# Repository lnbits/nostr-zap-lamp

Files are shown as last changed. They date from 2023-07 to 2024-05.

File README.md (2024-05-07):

# Nostr Zap Lamp

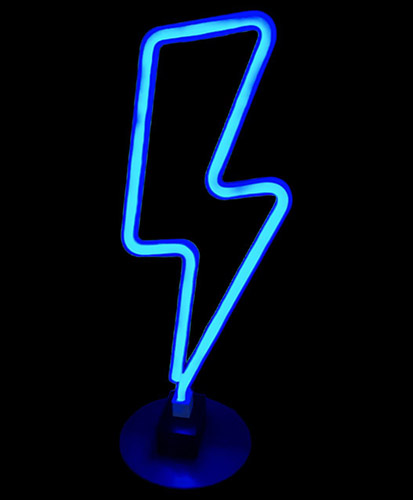
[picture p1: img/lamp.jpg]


Get a visual "Zap!"" when someone zaps you or anyone on Nostr.

The Nostr Zap Lamp flashes when a relay broadcasts a Nostr event of kind 9735. You can set the lamp to flash zaps sent to a specific npub, or any npub on nostr.

The number of flashes corresponds to the number of digits in the number of sats sent. i.e. 3 sats will result in 1 flash, 152 sats will result in 3 flashes, 1001 sats will result in 4 flashes.

[Buy a pre-assembled or complete Zap Lamp kit on the LNbits shop](https://shop.lnbits.com/product/nostr-zap-lamp)

# Features

+ Show a signal when a zap is sent to one or all nostr npubs
+ Background brightness control
+ Easily configure to use your own nostr relay
+ Simple configuration to work with any npub

## Parts
+ [LED "Neon" lamp](https://www.amazon.co.uk/YIVIYAR-Lightning-Battery-Bedroom-Christmas/dp/B08K4SCVKQ)
+ An ESP32 dev board
+ USB cable
+ A momentary switch push button - For example https://www.amazon.com/Momentary-Spring-Return-Self-Return-Pushbutton-Switches/dp/B09DJY5Y5L
+ Four jumper cables
+ Block connectors
+ A case. [This repo includes files for a 3D printed case](enclosure)

## Build Instructions

+ Identify the positive and negative leads of the lamp. Tie a knot in the +ve lead for future identification
+ Cut the lamp leads to around 10cm long
+ Attach a female jumper lead to each. Solder or use block connectors to attach the leads.
+ Attach female jumper leads to the push button
+ Connect the lamp to the ESP32: GPIO13 on the ESP32 -> lamp's positive wire and GND on the ESP32 -> lamp's negative wire.
+ Connect the push button button to the ESP32 on GPIO4 and GND
+ Install the lamp, ESP32, button and lead in the printed enclosure
+ Power on the device and configure using the WiFi access point portal.

## Firmware Upload Instructions

+ Use the web installer at https://nostr-zap-lamp.lnbits.com/ to flash and configure the device
+ Alternatively, use the Arduino IDE to flash the firmware.
    - Install the ESP32 board in the Arduino IDE by adding the following URL to the board manager: https://dl.espressif.com/dl/package_esp32_index.json
    - Install the following libraries using the Arduino IDE library manager:
        - uBitcoin
        - WebSockets
        - ArduinoJson
        - base64
        - WiFiManager
        - Nostr
    - Open the nostrZapLamp.ino file in the Arduino IDE
    - Select the ESP32 Dev Module board and the correct port
    - Compile and upload the firmware
    - Use the web installer at https://nostr-zap-lamp.lnbits.com/ to configure the device
        
## 5v Relay option

Using a 5v Relay the lamp will be brighter, or you can swap out the light and connect anything to the relay that you want to turn on.

ESP32 GND <==========================> Relay "DC-"

ESP32 5V <==========================> Relay "DC+"

LED POS <===========================> Relay "DC+"

ESP32 GND <=========================> Relay "COM"

LED GND <===========================> Relay "NO"

GPIO 13 <===========================> Relay "S"



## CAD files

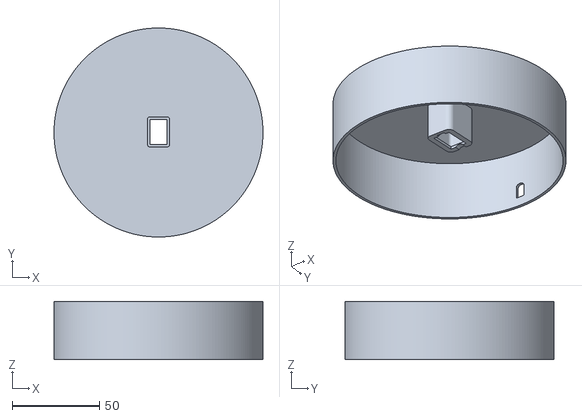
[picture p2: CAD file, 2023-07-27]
enclosure/Body.stl
120.0 x 120.0 x 33.5

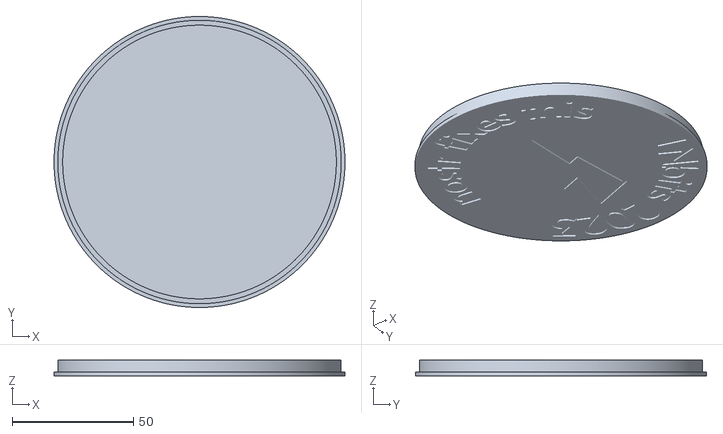
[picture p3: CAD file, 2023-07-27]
enclosure/Lid.stl
120.0 x 120.0 x 6.50

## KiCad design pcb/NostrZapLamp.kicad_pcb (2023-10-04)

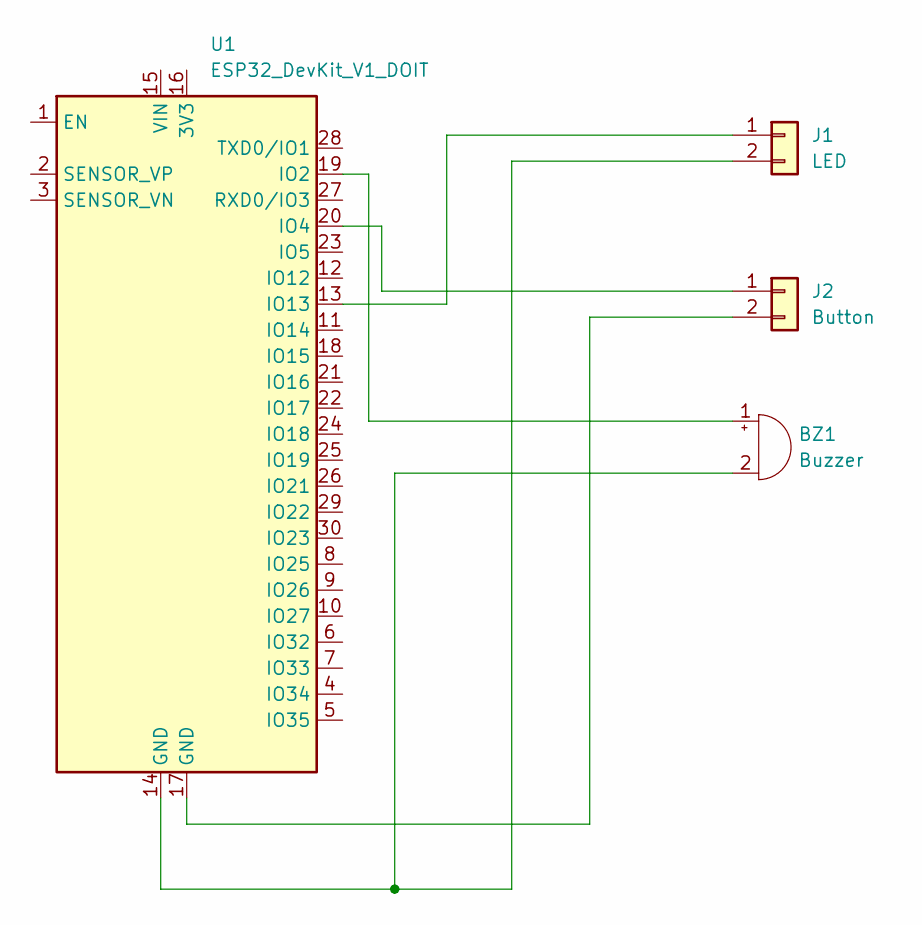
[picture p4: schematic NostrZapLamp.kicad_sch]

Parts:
BZ1: Buzzer; Buzzer_TDK_PS1240P02BT_D12.2mm_H6.5mm
J1: LED; PinHeader_1x02_P2.54mm_Vertical
J2: Button; PinHeader_1x02_P2.54mm_Vertical
U1: ESP32_DevKit_V1_DOIT; esp32_devkit_v1_doit

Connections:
unnamed: BZ1.2 (+), J1.2, U1.14 (GND)
unnamed: BZ1.1 (-), U1.19 (IO2)
unnamed: J1.1, U1.13 (IO13)
unnamed: J2.1, U1.20 (IO4)
unnamed: J2.2, U1.17 (GND)

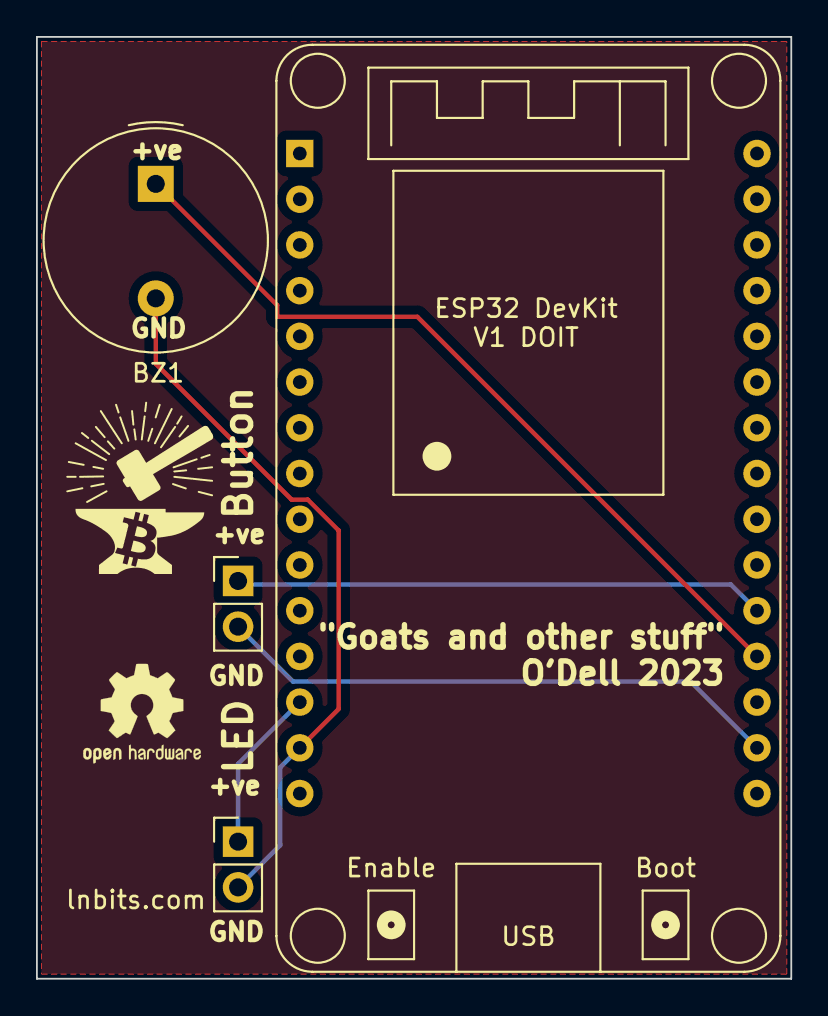
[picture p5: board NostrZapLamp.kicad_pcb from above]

Board: 2 copper layers, 41.9 x 52.3 mm, 4 parts (0 on the bottom side), 5 nets.

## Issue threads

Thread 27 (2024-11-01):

Compile errors after Arduino IDE and libraries update

Sebastix, 2024-11-01:
I've updated Arduino IDE from `2.3.2` to `2.3.3` and the installed libraries:

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

Now when I try to verify/compile the .ino file:

```sh
In file included from /home/sebastian/Arduino/libraries/uBitcoin/src/Bitcoin.h:11,
                 from /home/sebastian/Arduino/libraries/Nostr/src/NostrEvent.h:15,
                 from /home/sebastian/Desktop/Nostr Zap Lamp/nostr-zap-lamp/nostrZapLamp/nostrZapLamp.ino:23:
/home/sebastian/Arduino/libraries/uBitcoin/src/Networks.h:42:3: error: 'typedef struct Network Network' redeclared as different kind of entity
   42 | } Network;
      |   ^~~~~~~
In file included from /home/sebastian/.arduino15/packages/esp32/hardware/esp32/3.0.5/libraries/Network/src/Network.h:10,
                 from /home/sebastian/.arduino15/packages/esp32/hardware/esp32/3.0.5/libraries/WiFi/src/WiFiGeneric.h:39,
                 from /home/sebastian/.arduino15/packages/esp32/hardware/esp32/3.0.5/libraries/WiFi/src/WiFiSTA.h:29,
                 from /home/sebastian/.arduino15/packages/esp32/hardware/esp32/3.0.5/libraries/WiFi/src/WiFi.h:33,
                 from /home/sebastian/Desktop/Nostr Zap Lamp/nostr-zap-lamp/nostrZapLamp/nostrZapLamp.ino:21:
/home/sebastian/.arduino15/packages/esp32/hardware/esp32/3.0.5/libraries/Network/src/NetworkManager.h:34:23: note: previous declaration 'NetworkManager Network'
   34 | extern NetworkManager Network;
      |                       ^~~~~~~
/home/sebastian/Arduino/libraries/uBitcoin/src/Networks.h:44:14: error: 'Network' does not name a type; did you mean 'NetworkUDP'?
   44 | extern const Network Mainnet;
      |              ^~~~~~~
      |              NetworkUDP
/home/sebastian/Arduino/libraries/uBitcoin/src/Networks.h:45:14: error: 'Network' does not name a type; did you mean 'NetworkUDP'?
   45 | extern const Network Testnet;
      |              ^~~~~~~
      |              NetworkUDP
/home/sebastian/Arduino/libraries/uBitcoin/src/Networks.h:46:14: error: 'Network' does not name a type; did you mean 'NetworkUDP'?
   46 | extern const Network Regtest;
      |              ^~~~~~~
      |              NetworkUDP
/home/sebastian/Arduino/libraries/uBitcoin/src/Networks.h:47:14: error: 'Network' does not name a type; did you mean 'NetworkUDP'?
   47 | extern const Network Signet;
      |              ^~~~~~~
      |              NetworkUDP
/home/sebastian/Arduino/libraries/uBitcoin/src/Networks.h:49:14: error: 'Network' does not name a type; did you mean 'NetworkUDP'?
   49 | extern const Network * networks[];
      |              ^~~~~~~
      |              NetworkUDP
/home/sebastian/Arduino/libraries/uBitcoin/src/Bitcoin.h:117:54: error: 'Network' does not name a type; did you mean 'NetworkUDP'?
  117 |     int legacyAddress(char * addr, size_t len, const Network * network = &DEFAULT_NETWORK) const;
      |                                                      ^~~~~~~
      |                                                      NetworkUDP
/home/sebastian/Arduino/libraries/uBitcoin/src/Bitcoin.h:121:54: error: 'Network' does not name a type; did you mean 'NetworkUDP'?
  121 |     int segwitAddress(char * addr, size_t len, const Network * network = &DEFAULT_NETWORK) const;
      |                                                      ^~~~~~~
      |                                                      NetworkUDP
/home/sebastian/Arduino/libraries/uBitcoin/src/Bitcoin.h:125:60: error: 'Network' does not name a type; did you mean 'NetworkUDP'?
  125 |     int nestedSegwitAddress(char * addr, size_t len, const Network * network = &DEFAULT_NETWORK) const;
      |                                                            ^~~~~~~
      |                                                            NetworkUDP
/home/sebastian/Arduino/libraries/uBitcoin/src/Bitcoin.h:129:51: error: 'Network' does not name a type; did you mean 'NetworkUDP'?
  129 |     int address(char * address, size_t len, const Network * network = &DEFAULT_NETWORK) const{ return legacyAddress(address, len, network); };
      |                                                   ^~~~~~~
      |                                                   NetworkUDP
/home/sebastian/Arduino/libraries/uBitcoin/src/Bitcoin.h:131:32: error: 'Network' does not name a type; did you mean 'NetworkUDP'?
  131 |     String legacyAddress(const Network * network = &DEFAULT_NETWORK) const;
      |                                ^~~~~~~
      |                                NetworkUDP
/home/sebastian/Arduino/libraries/uBitcoin/src/Bitcoin.h:132:32: error: 'Network' does not name a type; did you mean 'NetworkUDP'?
  132 |     String segwitAddress(const Network * network = &DEFAULT_NETWORK) const;
      |                                ^~~~~~~
      |                                NetworkUDP
/home/sebastian/Arduino/libraries/uBitcoin/src/Bitcoin.h:133:38: error: 'Network' does not name a type; did you mean 'NetworkUDP'?
  133 |     String nestedSegwitAddress(const Network * network = &DEFAULT_NETWORK) const;
      |                                      ^~~~~~~
      |                                      NetworkUDP
/home/sebastian/Arduino/libraries/uBitcoin/src/Bitcoin.h:134:26: error: 'Network' does not name a type; did you mean 'NetworkUDP'?
  134 |     String address(const Network * network = &DEFAULT_NETWORK) const{ return legacyAddress(network); };
      |                          ^~~~~~~
      |                          NetworkUDP
In file included from /home/sebastian/Arduino/libraries/uBitcoin/src/Bitcoin.h:7:
/home/sebastian/Arduino/libraries/uBitcoin/src/uBitcoin_conf.h:5:25: error: 'Mainnet' was not declared in this scope
    5 | #define DEFAULT_NETWORK Mainnet
      |                         ^~~~~~~
/home/sebastian/Arduino/libraries/uBitcoin/src/Bitcoin.h:117:75: note: in expansion of macro 'DEFAULT_NETWORK'
  117 |     int legacyAddress(char * addr, size_t len, const Network * network = &DEFAULT_NETWORK) const;
      |                                                                           ^~~~~~~~~~~~~~~
/home/sebastian/Arduino/libraries/uBitcoin/src/uBitcoin_conf.h:5:25: error: 'Mainnet' was not declared in this scope
    5 | #define DEFAULT_NETWORK Mainnet
      |                         ^~~~~~~
/home/sebastian/Arduino/libraries/uBitcoin/src/Bitcoin.h:121:75: note: in expansion of macro 'DEFAULT_NETWORK'
  121 |     int segwitAddress(char * addr, size_t len, const Network * network = &DEFAULT_NETWORK) const;
      |                                                                           ^~~~~~~~~~~~~~~
/home/sebastian/Arduino/libraries/uBitcoin/src/uBitcoin_conf.h:5:25: error: 'Mainnet' was not declared in this scope
    5 | #define DEFAULT_NETWORK Mainnet
      |                         ^~~~~~~
/home/sebastian/Arduino/libraries/uBitcoin/src/Bitcoin.h:125:81: note: in expansion of macro 'DEFAULT_NETWORK'
  125 |     int nestedSegwitAddress(char * addr, size_t len, const Network * network = &DEFAULT_NETWORK) const;
      |                                                                                 ^~~~~~~~~~~~~~~
/home/sebastian/Arduino/libraries/uBitcoin/src/uBitcoin_conf.h:5:25: error: 'Mainnet' was not declared in this scope
    5 | #define DEFAULT_NETWORK Mainnet
      |                         ^~~~~~~
/home/sebastian/Arduino/libraries/uBitcoin/src/Bitcoin.h:129:72: note: in expansion of macro 'DEFAULT_NETWORK'
  129 |     int address(char * address, size_t len, const Network * network = &DEFAULT_NETWORK) const{ return legacyAddress(address, len, network); };
      |                                                                        ^~~~~~~~~~~~~~~
/home/sebastian/Arduino/libraries/uBitcoin/src/uBitcoin_conf.h:5:25: error: 'Mainnet' was not declared in this scope
    5 | #define DEFAULT_NETWORK Mainnet
      |                         ^~~~~~~
/home/sebastian/Arduino/libraries/uBitcoin/src/Bitcoin.h:131:53: note: in expansion of macro 'DEFAULT_NETWORK'
  131 |     String legacyAddress(const Network * network = &DEFAULT_NETWORK) const;
      |                                                     ^~~~~~~~~~~~~~~
/home/sebastian/Arduino/libraries/uBitcoin/src/uBitcoin_conf.h:5:25: error: 'Mainnet' was not declared in this scope
    5 | #define DEFAULT_NETWORK Mainnet
      |                         ^~~~~~~
/home/sebastian/Arduino/libraries/uBitcoin/src/Bitcoin.h:132:53: note: in expansion of macro 'DEFAULT_NETWORK'
  132 |     String segwitAddress(const Network * network = &DEFAULT_NETWORK) const;
      |                                                     ^~~~~~~~~~~~~~~
/home/sebastian/Arduino/libraries/uBitcoin/src/uBitcoin_conf.h:5:25: error: 'Mainnet' was not declared in this scope
    5 | #define DEFAULT_NETWORK Mainnet
      |                         ^~~~~~~
/home/sebastian/Arduino/libraries/uBitcoin/src/Bitcoin.h:133:59: note: in expansion of macro 'DEFAULT_NETWORK'
  133 |     String nestedSegwitAddress(const Network * network = &DEFAULT_NETWORK) const;
      |                                                           ^~~~~~~~~~~~~~~
/home/sebastian/Arduino/libraries/uBitcoin/src/uBitcoin_conf.h:5:25: error: 'Mainnet' was not declared in this scope
    5 | #define DEFAULT_NETWORK Mainnet
      |                         ^~~~~~~
/home/sebastian/Arduino/libraries/uBitcoin/src/Bitcoin.h:134:47: note: in expansion of macro 'DEFAULT_NETWORK'
  134 |     String address(const Network * network = &DEFAULT_NETWORK) const{ return legacyAddress(network); };
      |                                               ^~~~~~~~~~~~~~~
/home/sebastian/Arduino/libraries/uBitcoin/src/Bitcoin.h:170:80: error: 'Network' does not name a type; did you mean 'NetworkUDP'?
  170 |     PrivateKey(const uint8_t secret_arr[32], bool use_compressed = true, const Network * net = &DEFAULT_NETWORK);
      |                                                                                ^~~~~~~
      |                                                                                NetworkUDP
/home/sebastian/Arduino/libraries/uBitcoin/src/Bitcoin.h:186:11: error: 'Network' does not name a type; did you mean 'NetworkUDP'?
  186 |     const Network * network;
      |           ^~~~~~~
      |           NetworkUDP
/home/sebastian/Arduino/libraries/uBitcoin/src/uBitcoin_conf.h:5:25: error: 'Mainnet' was not declared in this scope
    5 | #define DEFAULT_NETWORK Mainnet
      |                         ^~~~~~~
/home/sebastian/Arduino/libraries/uBitcoin/src/Bitcoin.h:170:97: note: in expansion of macro 'DEFAULT_NETWORK'
  170 |     PrivateKey(const uint8_t secret_arr[32], bool use_compressed = true, const Network * net = &DEFAULT_NETWORK);
      |                                                                                                 ^~~~~~~~~~~~~~~
/home/sebastian/Arduino/libraries/uBitcoin/src/Bitcoin.h:258:24: error: 'Network' does not name a type; did you mean 'NetworkUDP'?
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
blackcoffeexbt, 2024-11-02:
Odd. Did it compile with 2.3.2?

Do you have vs code with platformio extension installed? Can you try building using that if so?

Sebastix, 2024-11-05:
I'm using the Arduino IDE and don't have any VScode based IDE installed.
I just tried version 2.3.2 and also replaced the updates libraries which older versions. But the same errors keep popping up. I think it's something related to my OS (laptop with Linux Mint),

I tried another compile on my MacOS device with Arduino 2.3.2 where I didn't do any updates since I was building the zaplamp (back in May this year) and there everything works as expected.

These are the current packages / libraries which could be updated:
- esp32 v2.0.11 by espressif systems
- arduinojson v7.0.4
- nostr v0.2.0
- websockets v2.4.0

Sebastix, 2024-11-05:
See https://github.com/nostrver-se/nostr-zap-lamp/commit/eb4fc9f08bc0b9fef5c6470fd9dd68ff89c2a2ed

dni, 2024-11-06:
hey, i fixed it here: https://github.com/lnbits/nostr-zap-lamp/pull/28

Closed 2024-11-06.

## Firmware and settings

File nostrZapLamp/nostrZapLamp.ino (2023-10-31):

///////////////////////////////////////////////////////////////////////////////////
//         Change these variables directly in the code or use the config         //
//  form in the web-installer https://lnbits.github.io/nostr-zap-lamp/installer/  //
///////////////////////////////////////////////////////////////////////////////////

String version = "0.0.1";

String config_ssid = "null"; // 'String config_ssid = "config_ssid";' / 'String config_ssid = "null";'
String config_wifi_password = "null"; // 'String config_wifi_password = "password";' / 'String config_wifi_password = "null";'
String config_pubkey = "null";
String config_relay = "null";

///////////////////////////////////////////////////////////////////////////////////
//                                 END of variables                              //
///////////////////////////////////////////////////////////////////////////////////

#include <WiFi.h>
#include "time.h"
#include <NostrEvent.h>
#include <NostrRelayManager.h>
#include <NostrRequestOptions.h>
#include <Wire.h>
#include "Bitcoin.h"
#include "Hash.h"
#include <esp_random.h>
#include <math.h>
#include <SPIFFS.h>
#include <vector>
#include <ArduinoJson.h>

// freertos
#include "freertos/FreeRTOS.h"
#include "freertos/task.h"

#define BUZZER_PIN 2      // Connect the piezo buzzer to this GPIO pin.
#define CLICK_DURATION 20 // Duration in milliseconds.

struct KeyValue {
    String key;
    String value;
};

int buttonPin = 4;
int portalPin = 15;
int triggerAp = false;

bool lastInternetConnectionState = true;

int socketDisconnectedCount = 0;
int ledPin = 13; // Pin number where the LED is connected
extern int buttonPin; // Pin number where the button is connected
int minFlashDelay = 100; // Minimum delay between flashes (in milliseconds)
int maxFlashDelay = 5000; // Maximum delay between flashes (in milliseconds)
int lightBrightness = 20; // The brightness of the LED (0-255)

bool forceConfig = false;

SemaphoreHandle_t zapMutex;

// create a vector for storing zap amount for the flash queue
std::vector<int> zapAmountsFlashQueue;

NostrEvent nostr;
NostrRelayManager nostrRelayManager;
NostrQueueProcessor nostrQueue;

String serialisedEventRequest;

bool hasInternetConnection = false;

NostrRequestOptions* eventRequestOptions;

bool hasSentEvent = false;

bool isBuzzerEnabled = false;

fs::SPIFFSFS &FlashFS = SPIFFS;
#define FORMAT_ON_FAIL true
#define PARAM_FILE "/elements.json"


// define funcs
void click(int period);
void configureAccessPoint();
void initWiFi();
bool whileCP(void);
void changeBrightness();
void signalWithLightning(int numFlashes, int duration);
void flashLightning(int zapAmountSats);
void doLightningFlash(int numberOfFlashes);
void initLamp();
unsigned long getUnixTimestamp();
void zapReceiptEvent(const std::string& key, const char* payload);
void okEvent(const std::string& key, const char* payload);
void relayConnectedEvent(const std::string& key, const std::string& message);
void relayDisonnectedEvent(const std::string& key, const std::string& message);
uint16_t getRandomNum(uint16_t min, uint16_t max);
void loadSettings();
int64_t getAmountInSatoshis(const String &input);
String getBolt11InvoiceFromEvent(String jsonStr);
void createZapEventRequest();
void connectToNostrRelays();

#define BUTTON_PIN 0 // change this to the pin your button is connected to
#define DOUBLE_TAP_DELAY 250 // delay for double tap in milliseconds

volatile unsigned long lastButtonPress = 0;
volatile bool doubleTapDetected = false;

void IRAM_ATTR handleButtonInterrupt() {
  unsigned long now = millis();
  if (now - lastButtonPress < DOUBLE_TAP_DELAY) {
    doubleTapDetected = true;
  }
  lastButtonPress = now;
}

//free rtos task for lamp control
void lampControlTask(void *pvParameters) {
  Serial.println("Starting lamp control task");
  attachInterrupt(digitalPinToInterrupt(BUTTON_PIN), handleButtonInterrupt, FALLING);

  for(;;) {
    if(!lastInternetConnectionState) {
      // slow fade pulse of LED
      for (int i = 100; i < 255; i++) {
        analogWrite(ledPin, i); // set the LED to the desired intensity
        delay(10);  // wait for a moment
      }
      // now fade out
      for (int i = 255; i >= 100; i--) {
        analogWrite(ledPin, i); // set the LED bright ness
        delay(10);  // wait for a moment
      }
    }

    // detect double tap on button
    if (doubleTapDetected) {
      Serial.println("Double tap detected. REstarting");
      // restart device
      ESP.restart();
    }

    // watch for button press and call changeBrightness
    if (digitalRead(buttonPin) == LOW && hasInternetConnection) {
      Serial.println("Button pressed. Changing brightness");
      changeBrightness();
    } else {

      // watch for lamp state and do as needed
      if (zapAmountsFlashQueue.size() > 0) {
        //  get size of queue and serial print all elements in queue
        Serial.println("There are " + String(zapAmountsFlashQueue.size()) + " zap(s) in the queue");
        xSemaphoreTake(zapMutex, portMAX_DELAY);
        int zapAmount = zapAmountsFlashQueue[0];
        zapAmountsFlashQueue.erase(zapAmountsFlashQueue.begin());
        xSemaphoreGive(zapMutex);

        // Click the buzzer zapAmount many times in a for loop with 100 ms delay
        for (int i = 0; i < zapAmount; i++) {
          click(225);
          delay(100);
        }
        doLightningFlash(zapAmount);

        // vTaskDelay(500 / portTICK_PERIOD_MS);
      }
      vTaskDelay(100 / portTICK_PERIOD_MS);
    }
  }
}

/**
 * @brief Create a Zap Event Request object
 *
 */
void createZapEventRequest() {
  // Create the REQ
  eventRequestOptions = new NostrRequestOptions();
  // Populate kinds
  int kinds[] = {9735};
  eventRequestOptions->kinds = kinds;
  eventRequestOptions->kinds_count = sizeof(kinds) / sizeof(kinds[0]);

  // // Populate #p
  Serial.println("npubHexString is |" + config_pubkey + "|");
  if(config_pubkey != "") {
    Serial.println("npub is specified");
    String* pubkeys = new String[1];  // Allocate memory dynamically
    pubkeys[0] = config_pubkey;
    eventRequestOptions->p = pubkeys;
    eventRequestOptions->p_count = 1;
  }

  eventRequestOptions->limit = 0;

  // We store this here for sending this request again if a socket reconnects
  serialisedEventRequest = "[\"REQ\", \"" + nostrRelayManager.getNewSubscriptionId() + "\"," + eventRequestOptions->toJson() + "]";

  delete eventRequestOptions;
}

/**
 * @brief Connect to the Nostr relays
 *
 */
void connectToNostrRelays() {
  // first disconnect from all relays
  nostrRelayManager.disconnect();
  Serial.println("Requesting Zap notifications");

  // split relays by comma into vector
  std::vector<String> relays;
  String relayStringCopy = config_relay;
  int commaIndex = relayStringCopy.indexOf(",");
  while (commaIndex != -1) {
    relays.push_back(relayStringCopy.substring(0, commaIndex));
    relayStringCopy = relayStringCopy.substring(commaIndex + 1);
    commaIndex = relayStringCopy.indexOf(",");
  }
  // add last item after last comma
  if (relayStringCopy.length() > 0) {
    relays.push_back(relayStringCopy);
  }

  // no need to convert to char* anymore
  nostr.setLogging(true);
  nostrRelayManager.setRelays(relays);
  nostrRelayManager.setMinRelaysAndTimeout(1,10000);

  // Set some event specific callbacks here
  Serial.println("Setting callbacks");
  nostrRelayManager.setEventCallback("ok", okEvent);
  nostrRelayManager.setEventCallback("connected", relayConnectedEvent);
  nostrRelayManager.setEventCallback("disconnected", relayDisonnectedEvent);
  nostrRelayManager.setEventCallback(9735, zapReceiptEvent);

  Serial.println("connecting");
  nostrRelayManager.connect();
}

bool adjustLightingBrightnessUp = true;
/**
 * @brief change lamp brightness
 *
 */
void changeBrightness() {
  // use lastLightingAdjustmentWasUp and max value of 255 to decide whether to adjust up or down
  if (adjustLightingBrightnessUp) {
    lightBrightness = lightBrightness + 5;
    if (lightBrightness >= 255) {
      lightBrightness = 255;
      adjustLightingBrightnessUp = false;
      // quick double flash to show at max brughtness
      Serial.println("Max brightness");
      delay(500); // pause to let the user take their finger off the button
    }
  } else {
    lightBrightness = lightBrightness - 5;
    if (lightBrightness <= 0) {
      lightBrightness = 0;
      adjustLightingBrightnessUp = true;
      Serial.println("Min brightness");
      delay(500); // pause to let the user take their finger off the button
    }
  }

  // write to spiffs
  File file = SPIFFS.open("/brightness.txt", FILE_WRITE);
  if(!file){
    Serial.println("Failed to open file for writing");
    return;
  }
  file.println(lightBrightness);
  file.close();

  analogWrite(ledPin, lightBrightness);
}

/**
 * @brief Flash the LED
 * 
 * @param numberOfFlashes 
 */
void doLightningFlash(int numberOfFlashes) {

  Serial.println("Flashing " + String(numberOfFlashes) + " times");

  // turn lamp off
  analogWrite(ledPin, lightBrightness / 3);

  delay(100);

  for(int flash = 1; flash <= numberOfFlashes; flash++) {
    // turn the LED on
    analogWrite(ledPin, 255);

    // wait for the specified time, longer for the first flash and shorter for subsequent flashes
    // int flashDuration = 250 / flash * random(1,5);
    int flashDuration = 250;
    delay(250);

    // fast fade-out
    for (int i = 255; i >= lightBrightness / 3; i = i - 2) {
      analogWrite(ledPin, i);  // set the LED brightness
      delay(1);  // wait for a moment
    }
    // analogWrite(ledPin, lightBrightness / 3);
    delay(250);
  }

  // fade from lightBrightness / 3 to lightBrightness
  for (int i = lightBrightness / 3; i <= lightBrightness; i = i + 1) {
    analogWrite(ledPin, i); // set the LED brightness
    delay(1);  // wait for a moment
  }

  delay(250);

  // set led to brightness
  analogWrite(ledPin, lightBrightness);
}

/**
 * @brief Add a zap amount to the flash queue
 * 
 * @param zapAmountSats 
 */
void flashLightning(int zapAmountSats) {
  int flashCount = 1;
  // set flash count length of the number in the zap amount
  if (zapAmountSats > 0) {
    flashCount = floor(log10(zapAmountSats)) + 1;
  }

  // push to the flash queue
  xSemaphoreTake(zapMutex, portMAX_DELAY);
  zapAmountsFlashQueue.push_back(flashCount);
  xSemaphoreGive(zapMutex);
}

/**
 * @brief Flash the LED a random number of times with a random delay between flashes
 *
 * @param numFlashes
 */
void signalWithLightning(int numFlashes, int duration = 500) {
  for (int i = 0; i < numFlashes; i++) {
    digitalWrite(ledPin, HIGH);
    delay(duration);

    digitalWrite(ledPin, LOW);
    delay(duration);
  }
}

/**
 * @brief Get the Unix Timestamp 
 * 
 * @return unsigned long 
 */
unsigned long getUnixTimestamp() {
  time_t now;
  struct tm timeinfo;
  if(!getLocalTime(&timeinfo)){
    Serial.println("Failed to obtain time");
    return 0;
  } else {
    Serial.println("Got timestamp of " + String(now));
  }
  time(&now);
  return now;
}

String lastPayload = "";

/**
 * @brief Event callback for when a relay connects
 * 
 * @param key 
 * @param message 
 */
void relayConnectedEvent(const std::string& key, const std::string& message) {
  socketDisconnectedCount = 0;
  Serial.println("Relay connected: ");

  click(225);
  delay(100);
  click(225);
  delay(100);
  click(225);

  Serial.print(F("Requesting events:"));
  Serial.println(serialisedEventRequest);

  nostrRelayManager.broadcastEvent(serialisedEventRequest);
}

/**
 * @brief Event callback for when a relay disconnects
 * 
 * @param key 
 * @param message 
 */
void relayDisonnectedEvent(const std::string& key, const std::string& message) {
  Serial.println("Relay disconnected: ");
  socketDisconnectedCount++;
  // reboot after 3 socketDisconnectedCount subsequenet messages
  if(socketDisconnectedCount >= 3) {
    Serial.println("Too many socket disconnections. Restarting");
    // restart device
    ESP.restart();
  }
}

/**
 * @brief Event callback for when a relay sends an OK event
 * 
 * @param key 
 * @param payload 
 */
void okEvent(const std::string& key, const char* payload) {
    if(lastPayload != payload) { // Prevent duplicate events from multiple relays triggering the same logic
      lastPayload = payload;
      Serial.println("payload is: ");
      Serial.println(payload);
    }
}

/**
 * @brief Get the Bolt11 Invoice From Event object
 * 
 * @param jsonStr 
 * @return String 
 */
String getBolt11InvoiceFromEvent(String jsonStr) {
  // Remove all JSON formatting characters
  String str = jsonStr.substring(1, jsonStr.length()-1); // remove the first and last square brackets
  str.replace("\\", ""); // remove all backslashes

  // Search for the "bolt11" substring
  int index = str.indexOf("bolt11");

  // Extract the value associated with "bolt11"
  String bolt11 = "";
  if (index != -1) {
    int start = index + 9; // the value of "bolt11" starts 9 characters after the substring index
    int end = start; // initialize the end index
    while (str.charAt(end) != '\"') {
      end++; // increment the end index until the closing double-quote is found
    }
    bolt11 = str.substring(start, end); // extract the value of "bolt11"
  }
  return bolt11;
}

/**
 * @brief Get the Amount In Satoshis from a lightning bol11 invoice
 *
 * @param input
 * @return int64_t
 */
int64_t getAmountInSatoshis(const String &input) {
    int64_t number = -1;
    char multiplier = ' ';

    for (unsigned int i = 0; i < input.length(); ++i) {
        if (isdigit(input[i])) {
            number = 0;
            while (isdigit(input[i])) {
                number = number * 10 + (input[i] - '0');
                ++i;
            }
            for (unsigned int j = i; j < input.length(); ++j) {
                if (isalpha(input[j])) {
                    multiplier = input[j];
                    break;
                }
            }
            break;
        }
    }

    if (number == -1 || multiplier == ' ') {
        return -1;
    }

    int64_t satoshis = number;

    switch (multiplier) {
        case 'm':
            satoshis *= 100000; // 0.001 * 100,000,000
            break;
        case 'u':
            satoshis *= 100; // 0.000001 * 100,000,000
            break;
        case 'n':
            satoshis /= 10; // 0.000000001 * 100,000,000
            break;
        case 'p':
            satoshis /= 10000; // 0.000000000001 * 100,000,000
            break;
        default:
            return -1;
    }

    return satoshis;
}

/**
 * @brief Get the Random Num object
 * 
 * @param min 
 * @param max 
 * @return uint16_t 
 */
uint16_t getRandomNum(uint16_t min, uint16_t max) {
  uint16_t rand  = (esp_random() % (max - min + 1)) + min;
  return rand;
}

/**
 * @brief Event callback for when a relay sends a zap receipt event
 * 
 * @param key 
 * @param payload 
 */
void zapReceiptEvent(const std::string& key, const char* payload) {
    if(lastPayload != payload) { // Prevent duplicate events from multiple relays triggering the same logic, as we are using multiple relays, this is likely to happen
      // define an array of phrases to use when a zap is a received
      String zapPhrases[] = {
        "Zap!",
        "A zap happened! ",
        "The zappenning!",
        "Zap! Zap!",
        "Pew pew!",
        "Zap! Zap! Zap!"
      };

      lastPayload = payload;
      String bolt11 = getBolt11InvoiceFromEvent(payload);
      // Serial.println("BOLT11: " + bolt11);
      uint64_t amountInSatoshis = getAmountInSatoshis(bolt11);
      // Choose a random phrase from the array
      int randomPhraseIndex = getRandomNum(0, sizeof(zapPhrases) / sizeof(zapPhrases[0]) - 1);
      Serial.println(zapPhrases[randomPhraseIndex] + " " + String(amountInSatoshis) + " sats");
      flashLightning(amountInSatoshis);
    }
}

/**
 * @brief Initialise the lamp
 * 
 */
void initLamp() {
  // Set the LED pin as OUTPUT
  pinMode(ledPin, OUTPUT);

  // get brightness value from spiffs brightness.txt
  File file = SPIFFS.open("/brightness.txt");
  if(!file){
    Serial.println("Failed to open file for reading");
    return;
  }
  String brightnessStr = file.readStringUntil('\n');
  file.close();
  lightBrightness = brightnessStr.toInt();

  // start lamp control task
  xTaskCreatePinnedToCore(
    lampControlTask,   /* Task function. */
    "lampControlTask",     /* String with name of task. */
    5000,            /* Stack size in bytes. */
    NULL,             /* Parameter passed as input of the task */
    2,                /* Priority of the task. */
    NULL,             /* Task handle. */
    1);               /* Core where the task should run */
}

/**
 * @brief Click a piezo buzzer if used
 * 
 * @param period 
 */
void click(int period)
{
  if(!isBuzzerEnabled) {
    return;
  }
  for (int i = 0; i < CLICK_DURATION; i++)
  {
    digitalWrite(BUZZER_PIN, HIGH);
    delayMicroseconds(period); // Half period of 1000Hz tone.
    digitalWrite(BUZZER_PIN, LOW);
    delayMicroseconds(period); // Other half period of 1000Hz tone.
  }
}

void setup() {
  Serial.begin(115200);
  Serial.println("boot");

  pinMode(buttonPin, INPUT_PULLUP); // Set the button pin as INPUT
  if(isBuzzerEnabled) {
    pinMode(BUZZER_PIN, OUTPUT); // Set the buzzer pin as an output.
    click(225);
  }

  FlashFS.begin(FORMAT_ON_FAIL);
  // init spiffs
  if(!SPIFFS.begin(true)){
    Serial.println("An Error has occurred while mounting SPIFFS");
    return;
  }

  initLamp();

  bool triggerConfig = false;
  int timer = 0;

  Serial.println("Should we trigger web serial config?");
  Serial.println("Touch pin (GPIO " + String(portalPin) + ") value is " + String(touchRead(portalPin)));
  Serial.println("Button pin (GPIO " + String(buttonPin) + ") value is " + String(digitalRead(buttonPin)));

  while (timer < 2000)
  {
    analogWrite(ledPin, 255);
    if (
      touchRead(portalPin) < 60
      ||
      digitalRead(buttonPin) == LOW
      )
    {
        triggerConfig = true;
        timer = 5000;
    }

    timer = timer + 100;
    delay(150);
    analogWrite(ledPin, 0);
    delay(150);
  }

  readFiles(); // get the saved details and store in global variables

  if(triggerConfig == true || config_ssid == "" || config_ssid == "null") {
    configOverSerialPort();
    hasInternetConnection = false;
  }
  else {
    WiFi.begin(config_ssid.c_str(), config_wifi_password.c_str());
    Serial.print("Connecting to WiFi");
    // connect for max of 15 seconds
    int wifiConnectTimer = 0;
    while (WiFi.status() != WL_CONNECTED && wifiConnectTimer < 15000) {
      delay(100);
      Serial.print(".");
      wifiConnectTimer = wifiConnectTimer + 100;
      hasInternetConnection = false;
    }
    if(WiFi.status() == WL_CONNECTED) {
      hasInternetConnection = true;
    }
    else {
      hasInternetConnection = false;
      configOverSerialPort();
    }

  }

  zapMutex = xSemaphoreCreateMutex();

  randomSeed(analogRead(0)); // Seed the random number generator

  createZapEventRequest();

  Serial.println("Connected to WiFi and got an IP");
  click(225);
  delay(100);
  click(225);
  connectToNostrRelays();

  // Set the LED to the desired intensity
  analogWrite(ledPin, lightBrightness);

}

String getJsonValue(JsonDocument &doc, const char* name)
{
    for (JsonObject elem : doc.as<JsonArray>()) {
        if (strcmp(elem["name"], name) == 0) {
            String value = elem["value"].as<String>();
            return value;
        }
    }
    return "";  // return empty string if not found
}
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
void loop() {
  // TESTING: fill the queue with some random zap amounts
  // for (int i = 0; i < 3; i++) {
  //   zapAmountsFlashQueue.push_back(getRandomNum(1,3));
  // }
  // delay(30000);

  nostrRelayManager.loop();
  nostrRelayManager.broadcastEvents();

  // reboot every hour
  if (millis() > 3600000) {
    Serial.println("Rebooting");
    ESP.restart();
  }
}

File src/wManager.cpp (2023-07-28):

#define ESP_DRD_USE_SPIFFS true

// Include Libraries
//#include ".h"
#include <WiFi.h>
#include <SPIFFS.h>
#include <FS.h>

#include <WiFiManager.h>
#include <ArduinoJson.h>
#include "wManager.h"

// JSON configuration file
#define JSON_CONFIG_FILE "/config.json"

// Flag for saving data
bool shouldSaveConfig = false;

int buttonPin = 4; // Pin number where the button is connected

// Variables to hold data from custom textboxes
char npubHexString[80] = "";
char relayString[80] = "legend.lnbits.com/nostrclient/api/v1/relay";

bool hasInternetConnection = false;

// Define WiFiManager Object
WiFiManager wm;

void saveConfigFile()
// Save Config in JSON format
{
  Serial.println(F("Saving configuration..."));
  
  // Create a JSON document
  StaticJsonDocument<512> json;
  json["npubHexString"] = npubHexString;
  json["relayString"] = relayString;

  // Open config file
  File configFile = SPIFFS.open(JSON_CONFIG_FILE, "w");
  if (!configFile)
  {
    // Error, file did not open
    Serial.println("failed to open config file for writing");
  }

  // Serialize JSON data to write to file
  serializeJsonPretty(json, Serial);
  if (serializeJson(json, configFile) == 0)
  {
    // Error writing file
    Serial.println(F("Failed to write to file"));
  }
  // Close file
  configFile.close();
}

bool loadConfigFile()
// Load existing configuration file
{
  // Uncomment if we need to format filesystem
  // SPIFFS.format();

  // Read configuration from FS json
  Serial.println("Mounting File System...");

  // May need to make it begin(true) first time you are using SPIFFS
  if (SPIFFS.begin(false) || SPIFFS.begin(true))
  {
    Serial.println("mounted file system");
    if (SPIFFS.exists(JSON_CONFIG_FILE))
    {
      // The file exists, reading and loading
      Serial.println("reading config file");
      File configFile = SPIFFS.open(JSON_CONFIG_FILE, "r");
      if (configFile)
      {
        Serial.println("Opened configuration file");
        StaticJsonDocument<512> json;
        DeserializationError error = deserializeJson(json, configFile);
        configFile.close();
        serializeJsonPretty(json, Serial);
        if (!error)
        {
          Serial.println("Parsing JSON");

          strcpy(npubHexString, json["npubHexString"]);
          strcpy(relayString, json["relayString"]);
          return true;
        }
        else
        {
          // Error loading JSON data
          Serial.println("Failed to load json config");
        }
      }
    }
  }
  else
  {
    // Error mounting file system
    Serial.println("Failed to mount FS");
  }

  return false;
}


void saveConfigCallback()
// Callback notifying us of the need to save configuration
{
  Serial.println("Should save config");
  shouldSaveConfig = true;
  //wm.setConfigPortalBlocking(false);
}

void configModeCallback(WiFiManager *myWiFiManager)
// Called when config mode launched
{
  Serial.println("Entered Configuration Mode");

  Serial.print("Config SSID: ");
  Serial.println(myWiFiManager->getConfigPortalSSID());

  Serial.print("Config IP Address: ");
  Serial.println(WiFi.softAPIP());
}

void init_WifiManager()
{
  Serial.begin(115200);
  //Serial.setTxTimeoutMs(10);

  //Init pin 15 to eneble 5V external power (LilyGo bug)
  pinMode(PIN_ENABLE5V, OUTPUT);
  digitalWrite(PIN_ENABLE5V, HIGH);

  // Change to true when testing to force configuration every time we run
  bool forceConfig = false;
  // Check if button is pressed to enter configMode with actual configuration
  if(digitalRead(buttonPin) == LOW){
    Serial.println(F("Forcing config mode"));
    forceConfig = true;
    wm.setBreakAfterConfig(true); //Set to detect config edition and save
 }
  bool spiffsSetup = loadConfigFile();
  if (!spiffsSetup)
  {
    Serial.println(F("Forcing config mode as there is no saved config"));
    forceConfig = true;    
  }

  // Explicitly set WiFi mode
  WiFi.mode(WIFI_STA);

  // Reset settings (only for development)
  //wm.resetSettings();

  //Set dark theme
  //wm.setClass("invert"); // dark theme
  
  // Set config save notify callback
  wm.setSaveConfigCallback(saveConfigCallback);

  // Set callback that gets called when connecting to previous WiFi fails, and enters Access Point mode
  wm.setAPCallback(configModeCallback);

  //Advanced settings
  wm.setConfigPortalBlocking(false); //Hacemos que el portal no bloquee el firmware
  wm.setConnectTimeout(50); // how long to try to connect for before continuing
  //wm.setConfigPortalTimeout(30); // auto close configportal after n seconds
  // wm.setCaptivePortalEnable(false); // disable captive portal redirection
  // wm.setAPClientCheck(true); // avoid timeout if client connected to softap
  //wm.setTimeout(120);
  //wm.setConfigPortalTimeout(120); //seconds
  
  // Custom elements

  // Text box (String) - 80 characters maximum
  WiFiManagerParameter npub_text_box("npubhex", "npub in hex format", npubHexString, 80);

  WiFiManagerParameter relay_text_box_num("relay", "Prefered relay", relayString, 80);

  // Add all defined parameters
  wm.addParameter(&npub_text_box);
  wm.addParameter(&relay_text_box_num);

  Serial.println("AllDone: ");
  if (forceConfig)
    // Run if we need a configuration
  {
    //No configuramos timeout al modulo
    wm.setConfigPortalBlocking(true); //Hacemos que el portal SI bloquee el firmware
    // tft.pushImage(0, 0, setupModeWidth, setupModeHeight, setupModeScreen);
    if (!wm.startConfigPortal("ZapLampAP","ZipZapZop"))
    {
      Serial.println("failed to connect and hit timeout");
      //Could be break forced after edditing, so save new config
      strncpy(npubHexString, npub_text_box.getValue(), sizeof(npubHexString));
      strncpy(relayString, relay_text_box_num.getValue(), sizeof(relayString));
      
      saveConfigFile();
      delay(3000);
      //reset and try again, or maybe put it to deep sleep
      ESP.restart();
      delay(5000);
    }
  }
  else
  {
    //Tratamos de conectar con la configuración inicial ya almacenada
    wm.setCaptivePortalEnable(false); // disable captive portal redirection
    if (!wm.autoConnect("ZapLampAP","ZipZapZop"))
    {
      Serial.println("Failed to connect and hit timeout");
      //delay(3000);
      // if we still have not connected restart and try all over again
      //ESP.restart();
      //delay(5000);
    }
  }

  //Conectado a la red Wifi
  if(WiFi.status() == WL_CONNECTED){
    //tft.pushImage(0, 0, MinerWidth, MinerHeight, MinerScreen);
    Serial.println("");
    Serial.println("WiFi connected");
    Serial.print("IP address: ");
    Serial.println(WiFi.localIP());

    hasInternetConnection = true;
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

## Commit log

2023-07-27 Added button brightness control and SPIFFs storage of setting
2023-07-27 Bug fix for npub watch in main and arduino nostr lib
    [main.cpp]
2023-07-27 Auto launch AP portal on button press on boot
2023-07-27 Added image to readme and enclosure stls
    [Body.stl, Lid.stl]
2023-07-28 Working through wifi connection issues...
    [main.cpp]
2023-07-28 All working well now. Needs tidiying up and Serial.prints removing
2023-07-29 Changed type of relays in NostrRelayManager to allow it to be set dynamically
2023-07-29 Work on reconnecting to relays after internet connection, but not router IP is lost
2023-07-30 Reboot on internet come back to reset all the things
    [main.cpp]
2023-07-31 Stability improvements and reboot on 3 relay disconnect messages
    [main.cpp]
2023-07-31 Rename relay label on AP to tell use to enter just one relay
2023-07-31 Reboot every hour to refresh relay connections
    [main.cpp]
2023-08-03 Remove nostr-arduino lib from repo and moved to dependency in platformio.ini
2023-08-10 Clear wifi settings when forcing device into AP mode
2023-08-10 actually reboot after 3 disconnects
    [main.cpp]
2023-10-04 Added KiCAD PCB layouts and gerber files and reorganised the repo
    [NostrZapLamp-B_Cu.gbr, NostrZapLamp-B_Silkscreen.gbr, NostrZapLamp-Edge_Cuts.gbr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]
2023-10-04 PCB tweaks. Update gitignore to exclude kicad locks
    [NostrZapLamp.kicad_pcb, NostrZapLamp.kicad_sch]
2023-10-04 Added quote to PCB
    [NostrZapLamp.kicad_pcb]
2023-10-04 Fixed design rule check issues
    [NostrZapLamp.kicad_pcb]
2023-10-04 Updated Gerber files
    [NostrZapLamp-B_Cu.gbr, NostrZapLamp-B_Silkscreen.gbr, NostrZapLamp-Edge_Cuts.gbr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]
2023-10-04 Added arrows for solder points to pcb
    [NostrZapLamp-B_Cu.gbr, NostrZapLamp-B_Silkscreen.gbr, NostrZapLamp-Edge_Cuts.gbr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]
2023-10-04 Added solder masks
    [NostrZapLamp-B_Cu.gbr, NostrZapLamp-B_Mask.gbr, NostrZapLamp-B_Silkscreen.gbr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]
2023-10-04 Change PCB holes to wider spacing for buzzer
    [NostrZapLamp-B_Cu.gbr, NostrZapLamp-B_Mask.gbr, NostrZapLamp-B_Silkscreen.gbr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]
2023-10-09 Added buzzer on pin 2
    [main.cpp]
2023-10-09 Added buzzer click on zap event.
    [main.cpp]
2023-10-09 Addded buzzer disable bool flag
    [main.cpp]
2023-10-30 add hardware-installer, github arduino workflows, release workflows (#10)
    moved code/ to nostrZapLamp
    renamed main.cpp to nostrZapLamp.ino
2023-10-30 Removed wManager and unused libs (QRCode ESP32Ping
2023-10-30 Bug fix for config launch
    [nostrZapLamp.ino]
2023-10-31 Various refactoring and bug fixes (#18)
    * Various refactoring and bug fixes
    * Various tweaks for configuration mode
    * Reduce inital brightness
    * Added fun phrases for zap receipts
    * Remove wifi connection state set in loop
    [100_config.ino, nostrZapLamp.ino]
2023-10-31 Fix Wifi connection timeout bug
    [nostrZapLamp.ino]
